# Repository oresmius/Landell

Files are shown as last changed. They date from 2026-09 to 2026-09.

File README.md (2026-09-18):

# Landell

Landell is an experimental software-defined radio (SDR) transceiver project under active development.

The project is named in honor of [Father Roberto Landell de Moura](https://memoria.ebc.com.br/agenciabrasil/noticia/2013-02-13/atualizada-invencao-que-pode-ser-atribuida-um-brasileiro-radio-se-integra-novas-tecnologias), a Brazilian Catholic priest, scientist, and inventor recognized as one of the early pioneers of radio and wireless voice transmission.

## Repository Structure

- `Arquivos Kicad/` — official hardware design, schematics, PCB, and project-specific symbol libraries.
- `Arquivos QSpice/` — simulation schematics, custom symbols, and SPICE models.
- `GNU Radio/` — flowgraphs, Python code, and test signals used in DSP experiments.
- `Documentos/` — project reports and technical conclusions.

## Current Work

Development currently focuses on the power supply, analog I/Q interface, signal conditioning, protection, grounding, circuit simulation, and SDR signal-processing experiments.

KiCad remains the official hardware schematic source. QSpice is used as a separate simulation environment.

## Status

Work in progress. Schematics, simulations, component choices, software, and documentation may change as the project evolves.

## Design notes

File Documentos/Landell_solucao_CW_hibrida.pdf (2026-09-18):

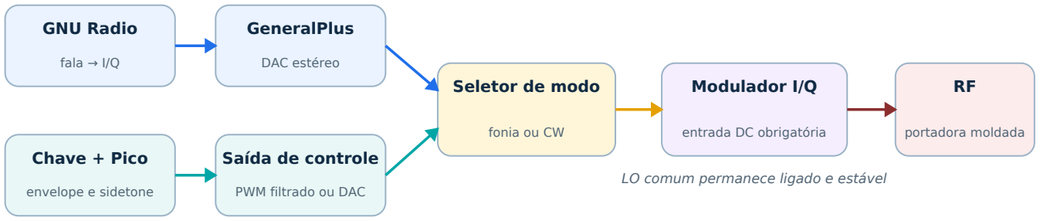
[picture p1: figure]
GNU Radio; fala → I/Q; GeneralPlus; DAC estéreo; Chave + Pico; envelope e sidetone; Saída de controle; PWM filtrado ou DAC; Seletor de modo; fonia ou CW; Modulador I/Q; entrada DC obrigatória; portadora moldada; LO comum permanece ligado e estável

PROJETO LANDELL | NOTA TÉCNICA CONCEITUAL | 11 set 2026 | 1

NOTA TÉCNICA • TRANSMISSÃO CW

# Solução CW híbrida com key shaping no Raspberry Pi Pico

### Proposta para reutilizar o oscilador e o modulador I/Q da fonia, mantendo a manipulação, o envelope da RF e o sidetone fora do caminho de latência do

computador.

DECISÃO CENTRAL: no modo CW, o Pico entrega I = A(t) e Q = 0 ao modulador I/Q. O sinal A(t) é o envelope suave da portadora.

DOIS MODOS, UM ÚNICO MODULADOR E UM ÚNICO OSCILADOR

CAT: configuração; a chave não depende do PC

Escopo e premissas

- O Landell não utilizará QSK; o equipamento permanece em transmissão durante a manipulação.
- A chave reta é lida localmente pelo Pico; cada fechamento não percorre CAT, Linux ou GNU Radio.
- O oscilador de RF permanece ligado e estável; apenas a amplitude da portadora é modelada.
- O documento termina na geração de RF de baixo nível; driver e amplificador de potência não fazem parte desta nota.

## 1. Arquitetura proposta

Na fonia SSB, o GNU Radio cria I/Q em banda-base e a GeneralPlus converte os dois canais para analógico. No CW, a placa de som deixa de ser necessária: o Pico cria diretamente uma tensão de envelope e um seletor analógico a encaminha ao mesmo modulador I/Q.

Aspecto | Fonia SSB | CW
Fonte | GNU Radio e GeneralPlus | Chave e Raspberry Pi Pico
Entrada I | Componente real do áudio | Envelope A(t)
Entrada Q | Componente em quadratura | Zero
Saída do modulador | Sinal SSB em RF | Portadora CW moldada
Temporização crítica | Não se aplica à fala | Executada localmente no Pico

Equação de funcionamento
s

### RF(t) = I(t) cos(ωc

### t) - Q(t) sin(ωc

t)
Para CW, fazemos I(t) = A(t) e Q(t) = 0. Portanto:

s

### RF(t) = A(t) cos(ωc

t)

Não há tom de 700 Hz no sinal transmitido. O sidetone é gerado separadamente e existe apenas para orientar o operador.

Um único cabo USB

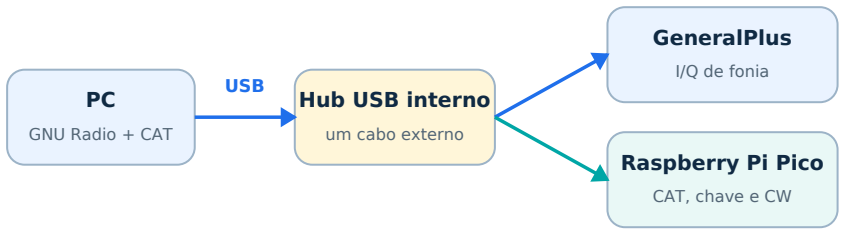
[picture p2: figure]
GNU Radio + CAT; Hub USB interno; um cabo externo; GeneralPlus; I/Q de fonia; Raspberry Pi Pico; CAT, chave e CW; USB

Um hub USB interno permite que GeneralPlus e Pico compartilhem um único cabo externo. O computador continua vendo dois dispositivos lógicos: áudio USB para fonia e porta serial CAT para controle. A chave permanece local ao rádio.

## 2. Key shaping controlado pelo Pico

O fechamento da chave não deve produzir uma mudança instantânea de amplitude. Bordas abruptas espalham energia para frequências adjacentes e produzem key clicks. O Pico substitui a transição vertical por rampas calculadas.

KEY SHAPING DIGITAL

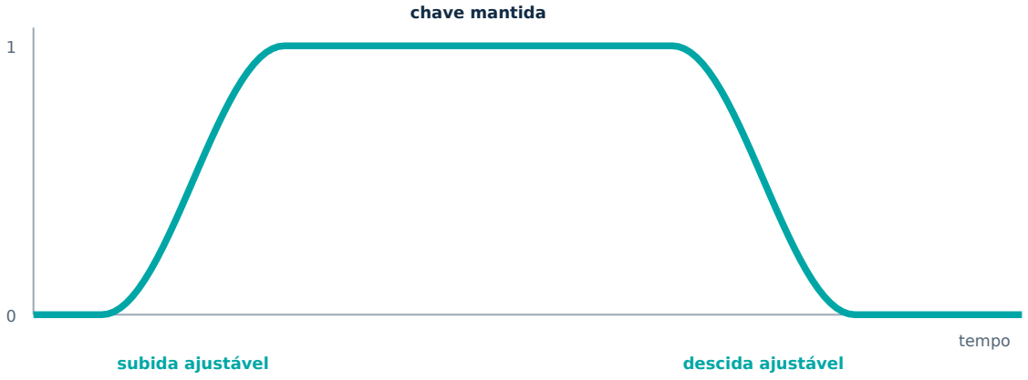
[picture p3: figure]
tempo; subida ajustável; chave mantida; descida ajustável

A RF segue A(t); o oscilador não é ligado e desligado pela chave.

Curva proposta

### A(t) = [1 - cos(πt/T)] / 2, para 0 ≤ t ≤ T

A expressão acima produz uma rampa de cosseno elevado. O valor T será ajustável por firmware. Uma faixa inicial de ensaio entre 2 e 10 ms é razoável, mas o valor final será escolhido por medição espectral e avaliação da manipulação.

Estado | Ação do Pico | Resultado na RF
Chave fecha | Inicia a rampa a partir do nível atual | Portadora cresce sem degrau
Chave permanece | Mantém A(t) no nível programado | Portadora constante
Chave abre | Inicia a descida a partir do nível atual | Portadora desaparece suavemente
Chave fecha durante a descida | Reverte a rampa sem reiniciar em zero | Sem descontinuidade ou clique

Sidetone

O sidetone é gerado localmente por outro PWM do Pico e segue o estado da chave sem atravessar o computador. Sua frequência e volume podem ser ajustáveis. Ele orienta o operador, mas não participa da RF transmitida.

## 3. Interface entre o Pico e o modulador

O Pico calcula A(t), mas ainda é necessário convertê-la em tensão analógica. Como o envelope varia lentamente, uma saída PWM filtrada pode ser suficiente. Um DAC externo permanece como alternativa se o ruído residual ou a linearidade do PWM forem inadequados.

Solução | Vantagem | Risco a verificar
PWM + filtro passa-baixas | Baixo custo e disponível no Pico | Ripple, tempo de acomodação e linearidade
DAC externo simples | Tensão limpa e previsível | Componente e interface adicionais

Requisitos do modulador I/Q

- Entradas I e Q devem aceitar banda-base acoplada em DC, incluindo valores estáticos.
- I = 0 e Q = 0 devem produzir o menor vazamento possível do oscilador local.
- A amplitude da saída deve acompanhar A(t) de forma monotônica e suficientemente linear.
- O seletor fonia/CW deve evitar que GeneralPlus e Pico dirijam simultaneamente as mesmas entradas.

Vazamento entre caracteres

Moduladores reais deixam escapar uma fração do LO mesmo com I e Q zerados. Se a calibração de zero não atingir o silêncio necessário, será incluída uma chave ou um atenuador de RF após o modulador. Esse elemento será usado somente para o estado ocioso; as bordas do CW continuarão sendo definidas pelo envelope do Pico.

Plano de contingência: se o modulador escolhido não aceitar DC, o CW contornará o modulador e usará um atenuador de RF controlado pelo mesmo envelope.

O que não será feito

- Não será construído um segundo oscilador independente apenas para CW.
- A temporização da chave não dependerá de CAT, GNU Radio ou buffers de áudio.
- O oscilador não será energizado e desenergizado a cada ponto ou traço.
- Não será implementado QSK.

## 4. Sequência de validação

A implementação deve avançar em baixa potência e com carga artificial. Cada etapa precisa ser validada antes da seguinte.

Etapa | Ensaio | Critério
1 | Entrada da chave | Confirmar leitura limpa da chave reta, sem falsos acionamentos e sem alterar a duração dos sinais.
2 | Sidetone local | Verificar resposta imediata, frequência confortável e ausência de dependência do computador.
3 | Envelope elétrico | Observar A(t) no osciloscópio; medir subida, sustentação, descida e reversão durante pulsos curtos.
4 | Modulador em DC | Confirmar que I = A(t), Q = 0 gera uma portadora na frequência do LO e que a amplitude acompanha a rampa.
5 | Vazamento do LO | Medir a portadora residual com a chave aberta e decidir se será necessário mute posterior.
6 | Espectro de manipulação | Comparar tempos de rampa e escolher o menor espalhamento compatível com manipulação confortável.
7 | Integração de modos | Confirmar que o seletor alterna fonia e CW sem conflito entre GeneralPlus e Pico.

Decisões ainda abertas

- Modelo e topologia do modulador I/Q, com confirmação de acoplamento em DC.
- PWM filtrado ou DAC para produzir A(t).
- Faixa final de tempos de subida e descida.
- Necessidade de chave ou atenuador adicional para eliminar vazamento do LO.
- Forma física do seletor entre I/Q da GeneralPlus e controle de CW do Pico.

RESULTADO ESPERADO: CW limpo, sem latência de manipulação do computador, usando o mesmo oscilador, o mesmo modulador I/Q e o mesmo caminho de RF da fonia.

Status

Esta nota registra uma solução conceitual. Nenhum modulador, seletor, filtro de PWM ou estágio de RF foi ainda escolhido ou construído. Os valores numéricos apresentados são pontos iniciais de ensaio, não especificações finais.

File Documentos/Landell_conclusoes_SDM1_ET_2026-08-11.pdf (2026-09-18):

Projeto Landell - Envelope Tracking / SDM1 | Página 1

# PROJETO LANDELL

Conclusões da campanha SDM1 aplicada ao Envelope Tracking de SSB

Status: investigação dos vales próximos de zero ENCERRADA

Data: 11 de agosto de 2026

Bancada: GNU Radio, SDM1 de 1ª ordem / 1 bit, 300 kS/s, envelope obtido por Hilbert + magnitude, reconstrução com LPF de 5 kHz.

Objetivo deste documento: registrar o que foi demonstrado experimentalmente, o que permanece apenas conceitual e quais decisões de engenharia podem ser tomadas sem entrar ainda no hardware do PA.

## Conclusão central

O SDM1 permanece tecnicamente viável para o Landell. O comportamento anômalo observado nos vales muito próximos de zero não se mostrou uma incapacidade geral de acompanhar a envoltória SSB. Foi identificado como uma consequência previsível da baixa densidade de pulsos de um modulador determinístico de 1 bit, combinada com a banda passante do filtro de reconstrução.

Não há, neste momento, justificativa experimental para migrar para SDM2, introduzir dithering ou aumentar a complexidade do modulador.

## 1. Estado da bancada no ensaio

O ensaio final introduziu apenas um piso matemático antes da bifurcação do caminho de referência e do caminho SDM. O bloco Max recebe a magnitude da envoltória e uma constante. Assim, os dois caminhos recebem exatamente o mesmo sinal limitado.

E_teste(t) = max(E(t), V_piso_normalizado)

O valor do piso é normalizado. Ele não representa tensão física e não define o Vmin futuro do PA.

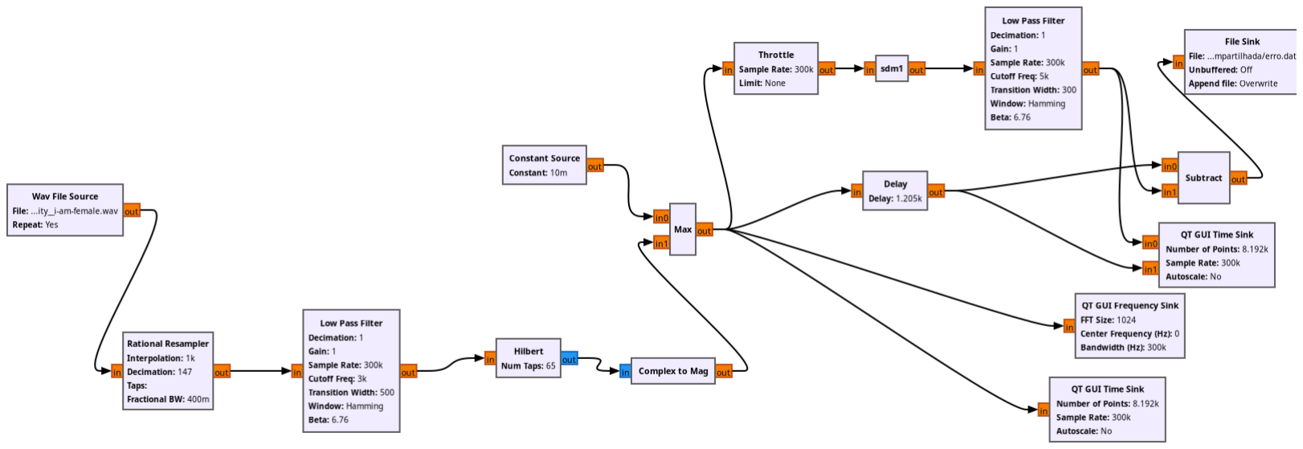
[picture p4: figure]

Figura 1 - Flowgraph do teste: Constant Source + Max antes da divisão para Delay, SDM1, Time Sink e Frequency Sink.

Parâmetro | Valor no ensaio
Taxa do SDM1 | 300 kS/s
Ordem / quantização | 1ª ordem / 1 bit
LPF pré-Hilbert | 3 kHz, transição 500 Hz
Hilbert | 65 taps
Delay de referência | 1205 amostras
LPF pós-SDM | 5 kHz, transição 300 Hz
Pisos testados | 0,01 e 0,02 (normalizados)

## 2. Diagnóstico do comportamento em baixa densidade

Com entrada constante muito pequena, o SDM1 precisa representar a média desejada por meio de poucos bits "1" separados por longas sequências de zeros. Como a implementação é determinística, essa baixa densidade pode adquirir uma periodicidade regular.

### Caso 0,01

Para uma entrada constante de 0,01, a densidade média requerida é de aproximadamente 1%. Isso corresponde, no caso ideal periódico, a cerca de um bit "1" a cada 100 amostras.

300 000 / 100 = 3 000 Hz

Essa estrutura cai em torno de 3 kHz, portanto dentro da banda passante do LPF pós-SDM de 5 kHz. Resultado observado: a referência fica parada em 0,01, mas a reconstrução apresenta uma ondulação periódica de grande amplitude relativa.

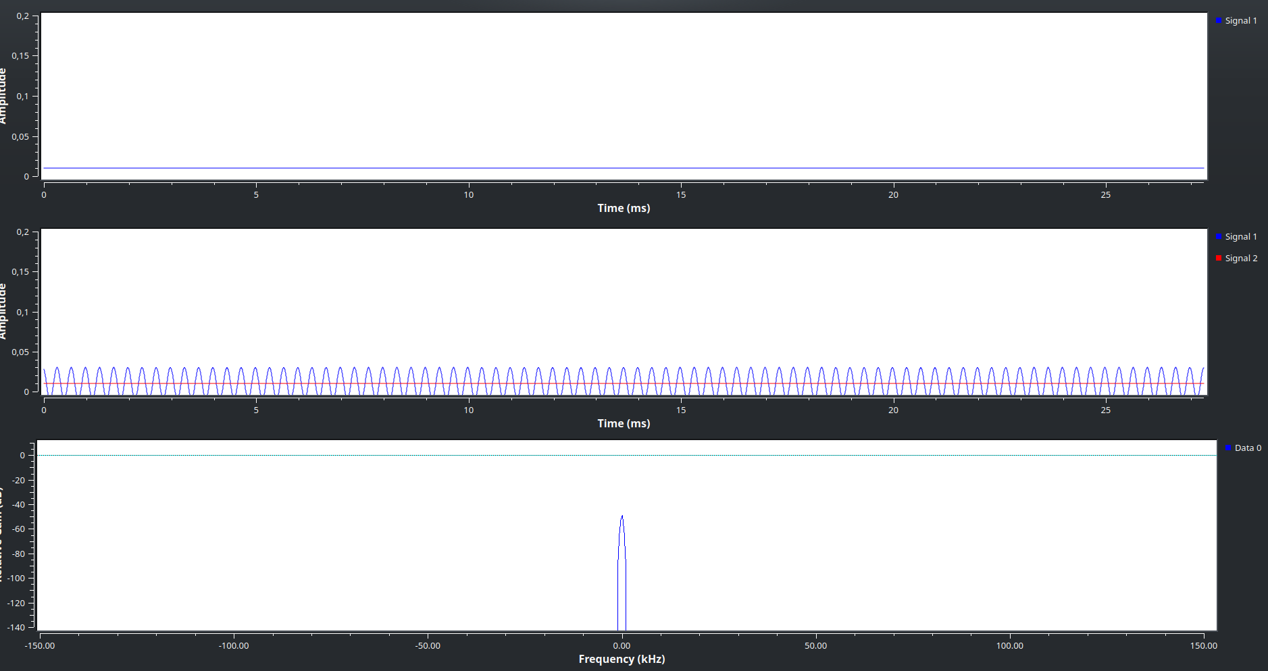
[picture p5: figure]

Figura 2 - Piso 0,01: no trecho constante, a referência permanece em 0,01 e a reconstrução do SDM1 exibe forte ondulação periódica.

### Caso 0,02

Ao elevar apenas o piso para 0,02, a densidade média passa a aproximadamente 2%, equivalente a cerca de um bit "1" a cada 50 amostras.

300 000 / 50 = 6 000 Hz

A periodicidade dominante desloca-se para aproximadamente 6 kHz, acima do corte de 5 kHz e já além da faixa de transição do filtro. O resultado experimental foi o previsto: a forte ondulação praticamente desapareceu.

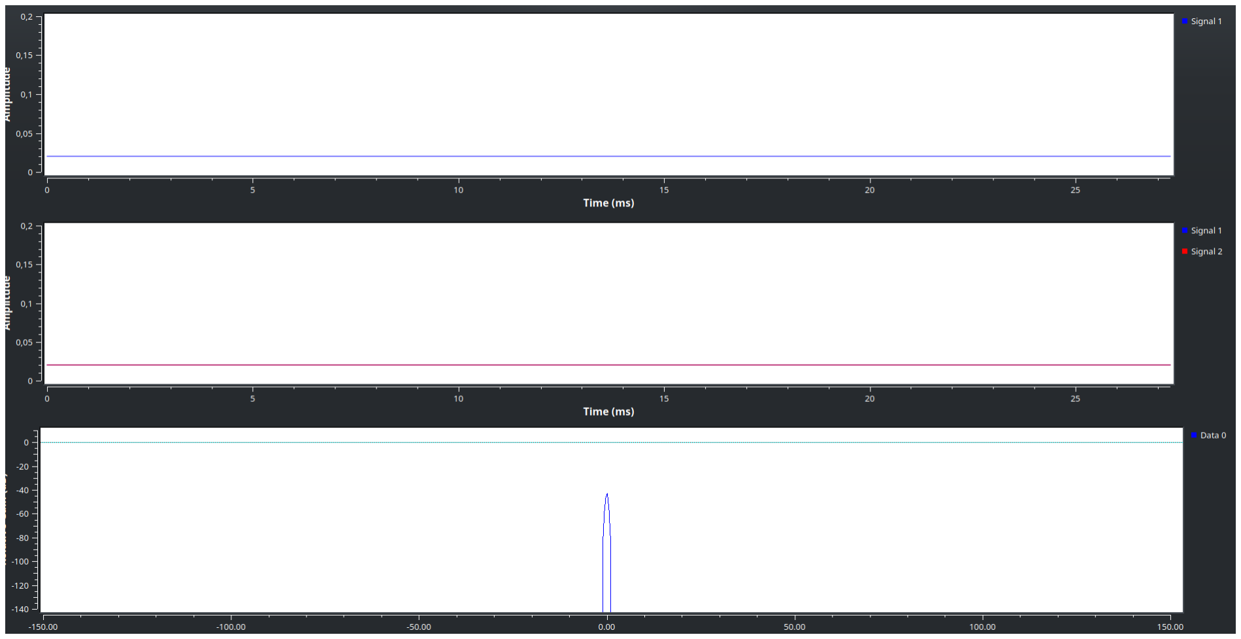
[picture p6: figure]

Figura 3 - Piso 0,02: referência e reconstrução ficam praticamente coincidentes no trecho constante.

## 3. Resultado com voz e envoltória SSB

O comportamento identificado no teste constante também explica os vales observados durante a voz. Nos níveis médios e altos da envoltória, o SDM1 já acompanhava muito bem a referência. O problema concentrava-se justamente nos vales de baixíssima amplitude.

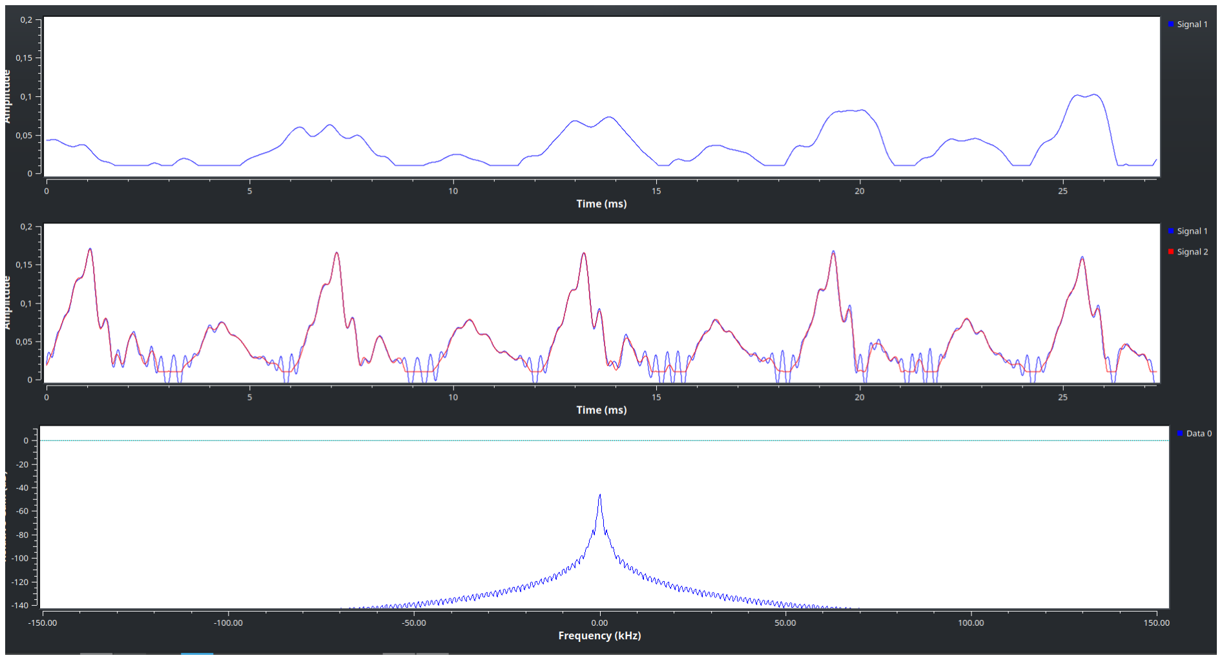
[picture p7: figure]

Figura 4 - Com piso 0,01, os vales ainda exibem forte estrutura periódica na reconstrução azul, enquanto a referência vermelha permanece limitada pelo piso.

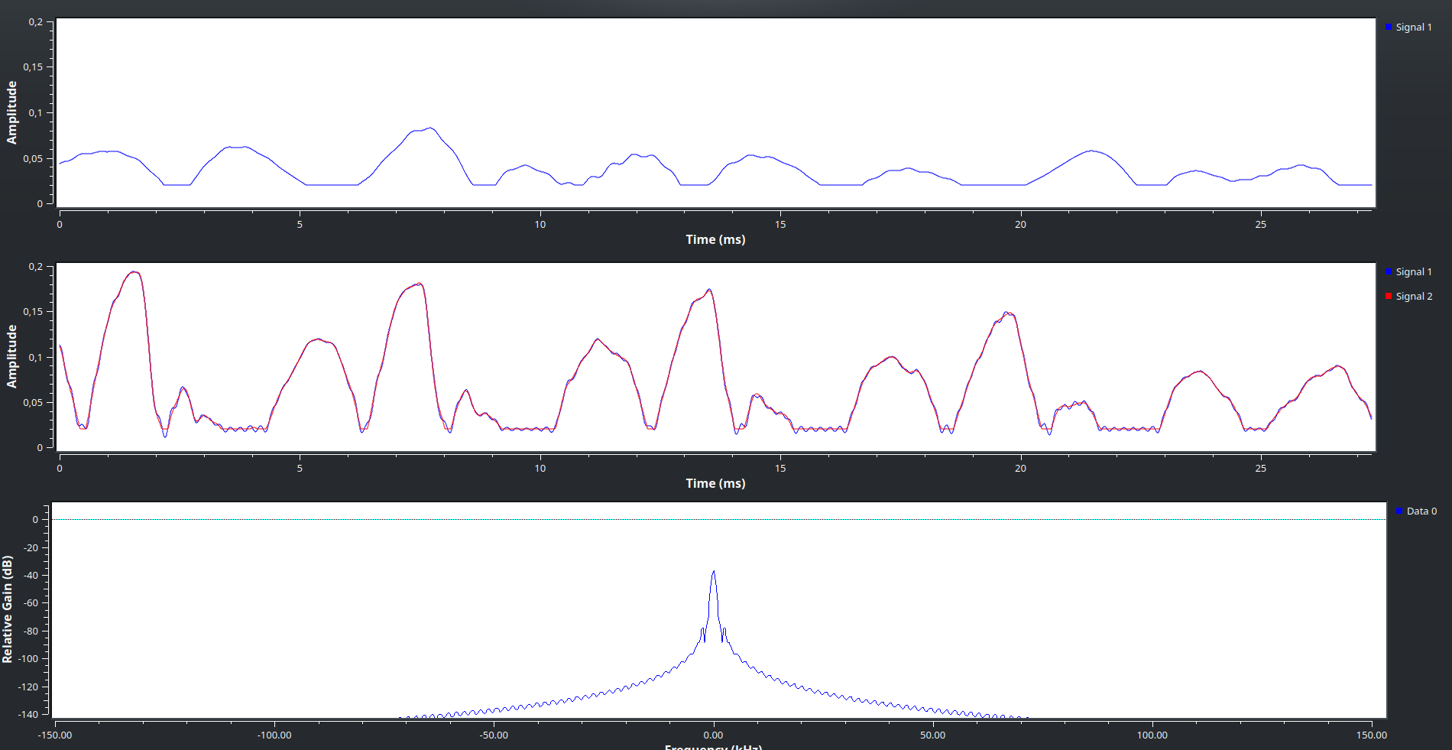
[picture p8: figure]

Figura 5 - Com piso 0,02, os vales ficam muito mais comportados e as curvas permanecem fortemente coincidentes na região útil.

Interpretação: o SDM1 não falhou em acompanhar a dinâmica da voz. O artefato observado era ligado à representação de amplitudes extremamente pequenas e à posição da periodicidade resultante em relação ao LPF de reconstrução.

## 4. Conclusões fechadas

- A campanha de senoides permanece encerrada. Os limites observados anteriormente foram atribuídos aos LPFs, não ao SDM1.
- O SDM1 de 1ª ordem e 1 bit a 300 kS/s continua adequado como solução simples. Não apareceu evidência de limitação geral na banda de voz considerada para SSB.
- O fenômeno dos vales foi identificado. Em densidades muito baixas, o SDM1 determinístico produz estrutura periódica que pode cair dentro da banda do filtro de reconstrução.
- O teste 0,01 -> 0,02 confirmou o mecanismo previsto. Ao deslocar a periodicidade dominante de aproximadamente 3 kHz para aproximadamente 6 kHz, a ondulação foi fortemente reduzida pelo LPF de 5 kHz.
- Não há motivo, neste ponto, para SDM2, dithering ou aumento de complexidade. Qualquer sofisticação futura deverá ser motivada por um problema real na faixa operacional, não pelo comportamento no zero ideal.
- Envelope zero não implica necessariamente alimentação zero do PA. O conceito de um piso Vmin permanece válido como elemento arquitetural; contudo, seu valor físico depende do PA e ainda não foi definido.

## 5. O que NÃO foi concluído

- 0,02 não é o Vmin do Landell. É apenas um valor normalizado de diagnóstico.
- Ainda não foi escolhido o transistor, a classe definitiva do PA, a tensão de alimentação nem o estágio físico de modulação da alimentação.
- Ainda não foi definida a arquitetura final do trilho de RF que produzirá a excitação SSB para pré-driver, driver e PA.
- O presente ensaio não mede eficiência global do transmissor, linearidade do PA, IMD, sincronismo RF/ET em hardware ou desempenho térmico.

## 6. Decisão de engenharia para a retomada

A investigação específica dos vales próximos de zero deve ser considerada encerrada. O SDM1 permanece como modulador candidato do trilho de Envelope Tracking. O bloco Max e o piso 0,02 pertencem ao ensaio diagnóstico e não devem ser confundidos com um parâmetro físico final.

Estado recomendado: manter o SDM1 simples; não iniciar nova campanha de varredura; avançar apenas quando houver uma pergunta de arquitetura ou de hardware claramente definida.

Registro técnico elaborado a partir do flowgraph atualizado, do código do SDM1 e das capturas dos ensaios realizados nesta campanha.

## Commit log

2026-09-18 Initial commit: Landell SDR transceiver project
    [Interface_IQ.kicad_sch, Landell.kicad_pcb, Landell.kicad_sch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]
2026-10-12 Testando no circuito os dois OPA2836
2026-10-15 Testes do QSE concluídos. Passando para o projeto de PA.
2026-10-18 Desenvolvimento do circuito de BIAS do PA
2026-10-20 Conclusão do circuito de BIAS do PA
2026-10-21 Teste do trafo de entrada do PA.
2026-10-23 Driver concluído e início do estágio final de amplificação de RF.
